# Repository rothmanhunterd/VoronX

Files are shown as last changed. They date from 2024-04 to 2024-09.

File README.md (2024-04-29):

# VoronX

VoronX is a large format 3D printer with a build volume of 800mm x 800mm by 800mm. This featues dual extruders which both run off 2.85mm filament. The 2.85mm filament enables larger nozzle sizes, for example the standard nozzle size for this printer is 2.4mm. This is a standard cartesian pritner with a flying gantry. The X and Y axis are driven independetly by two motors each. The Z axis is driven by 4 lead screws. This printer is configured with Klipper firmware and uses MainSail interface.

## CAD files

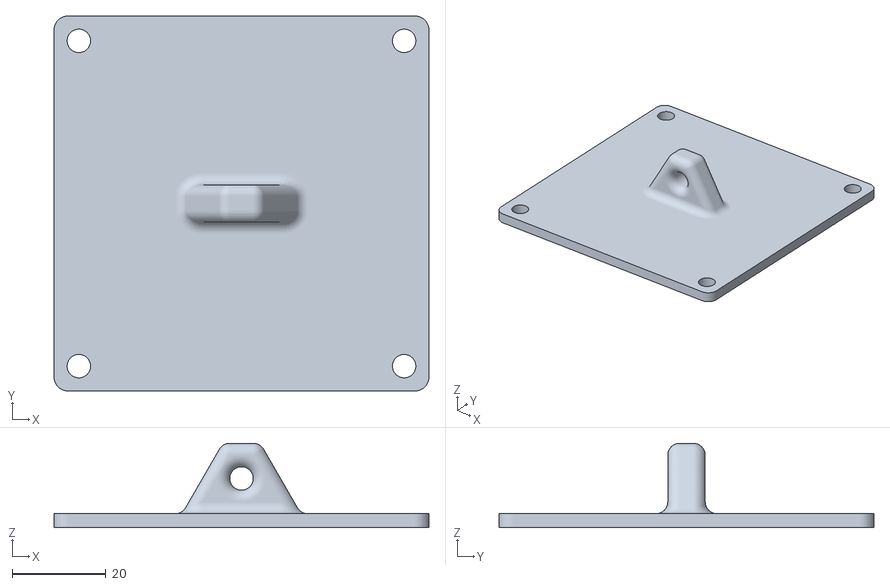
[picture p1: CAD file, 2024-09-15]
hardware/CAD_files/STLs/Counterweight/Weight_Top_Box.STL
80.0 x 80.0 x 18.0

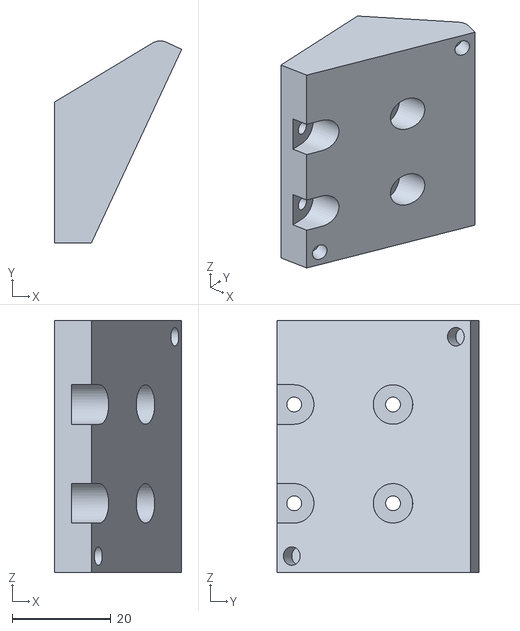
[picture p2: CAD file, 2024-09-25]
hardware/CAD_files/STLs/Part_Cooling_Fan/Part_Cooling_Mount_Left.STL
25.8 x 40.9 x 51.0

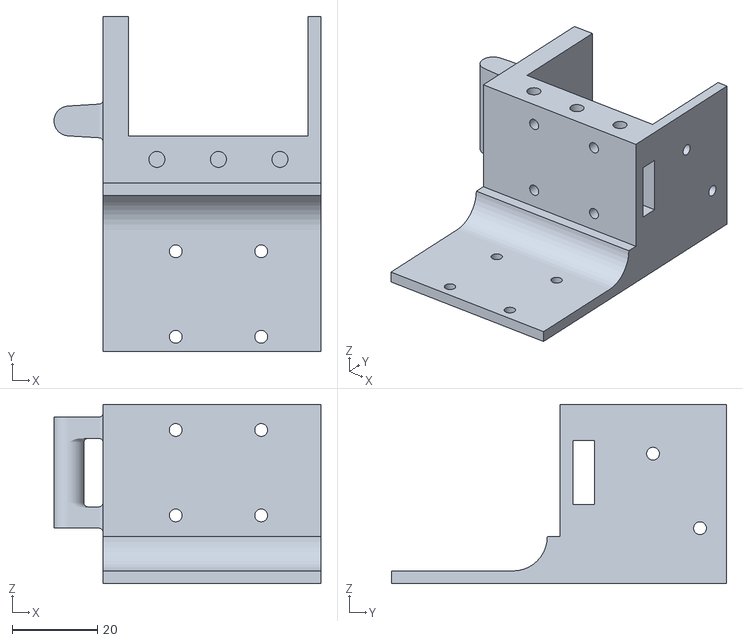
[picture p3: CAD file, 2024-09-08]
hardware/CAD_files/STLs/Print_Head_Mount_Right.STL
62.5 x 78.5 x 42.0

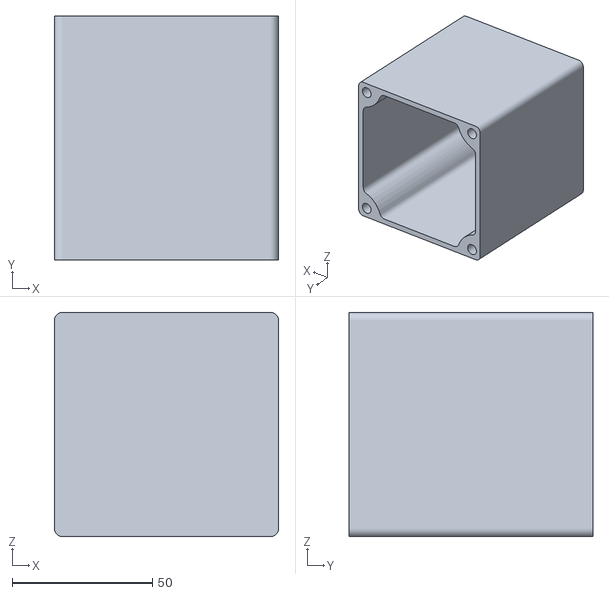
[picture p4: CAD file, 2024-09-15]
hardware/CAD_files/STLs/Counterweight/Weight_Bottom_Box.STL
80.0 x 87.0 x 80.0

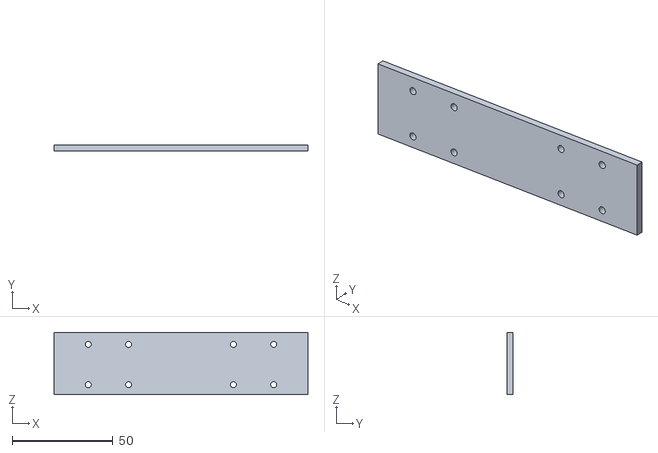
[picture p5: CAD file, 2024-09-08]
hardware/CAD_files/STLs/Connector_Plate.STL
126.0 x 3.00 x 31.0

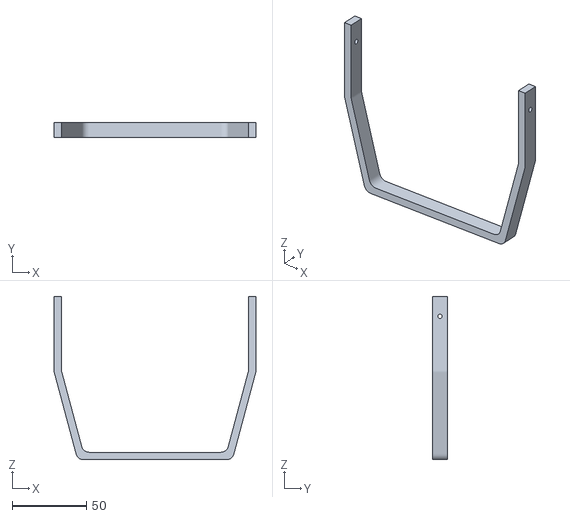
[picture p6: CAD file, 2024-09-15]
hardware/CAD_files/STLs/Counterweight/Tension_Bar.STL
136.0 x 10.0 x 110.0

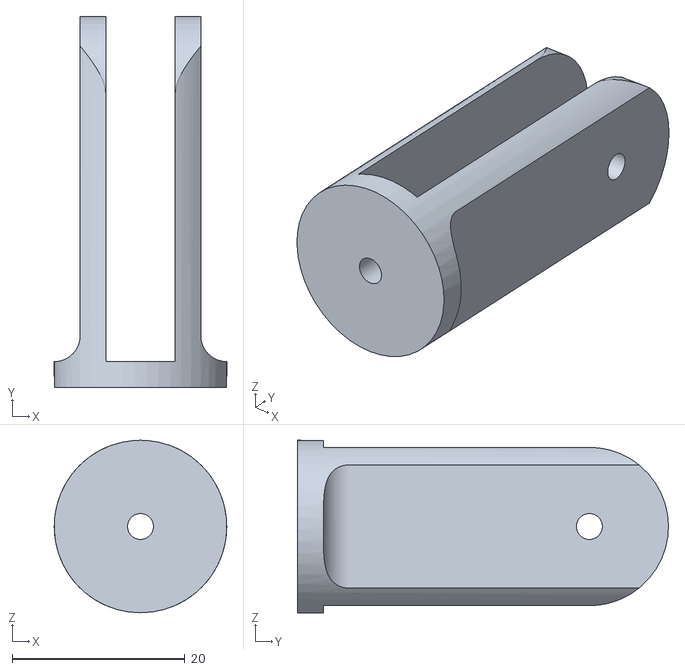
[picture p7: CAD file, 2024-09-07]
hardware/CAD_files/STLs/Cam_Frame_Mount.STL
20.0 x 43.0 x 20.0

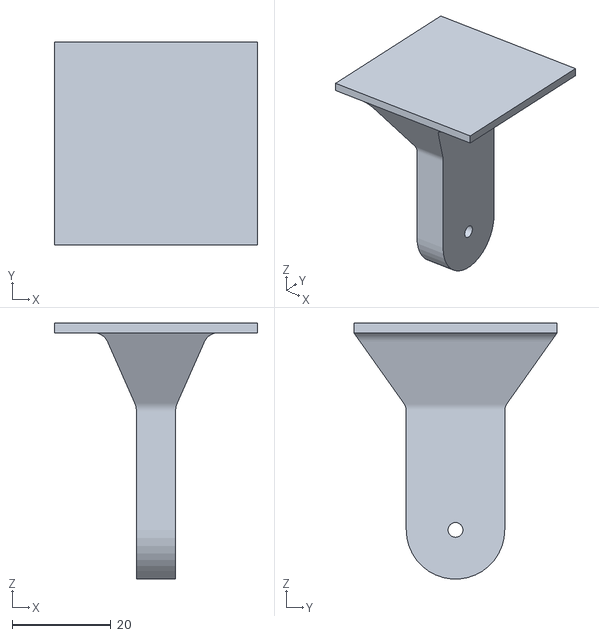
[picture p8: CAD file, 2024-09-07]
hardware/CAD_files/STLs/Cam_Cam_Mount.STL
41.3 x 41.3 x 52.0

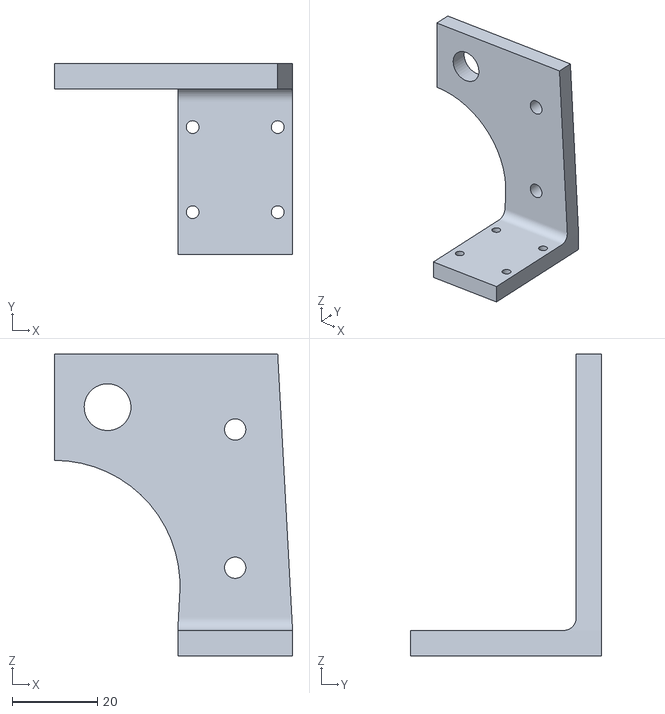
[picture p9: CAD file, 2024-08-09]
hardware/CAD_files/STLs/Gantry_Linear_Rail_Connector_Front_Left.STL
56.0 x 45.0 x 71.0

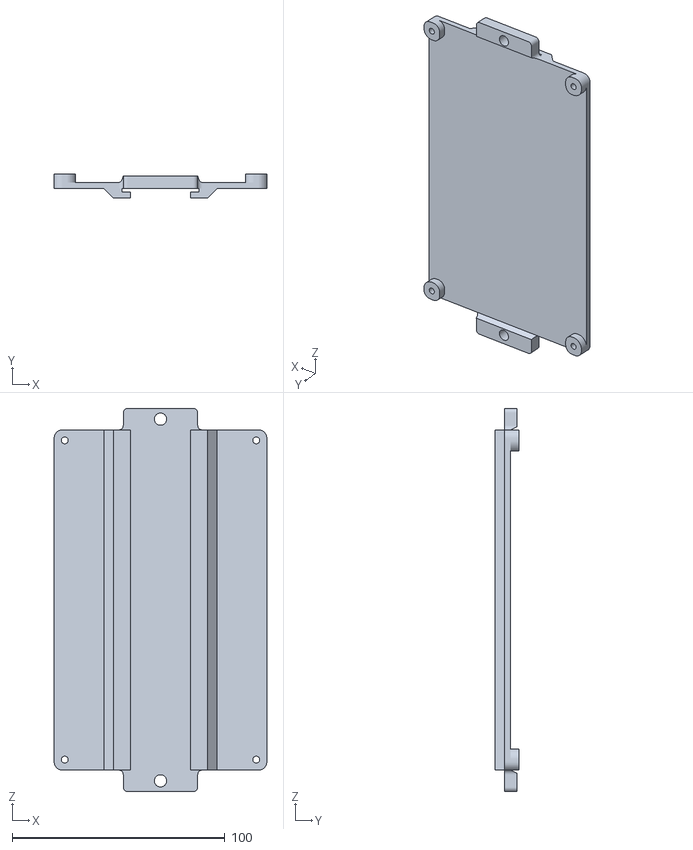
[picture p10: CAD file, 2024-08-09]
hardware/CAD_files/STLs/Octopus_Max_EZ_DIN_Mount.STL
100.0 x 11.5 x 180.0

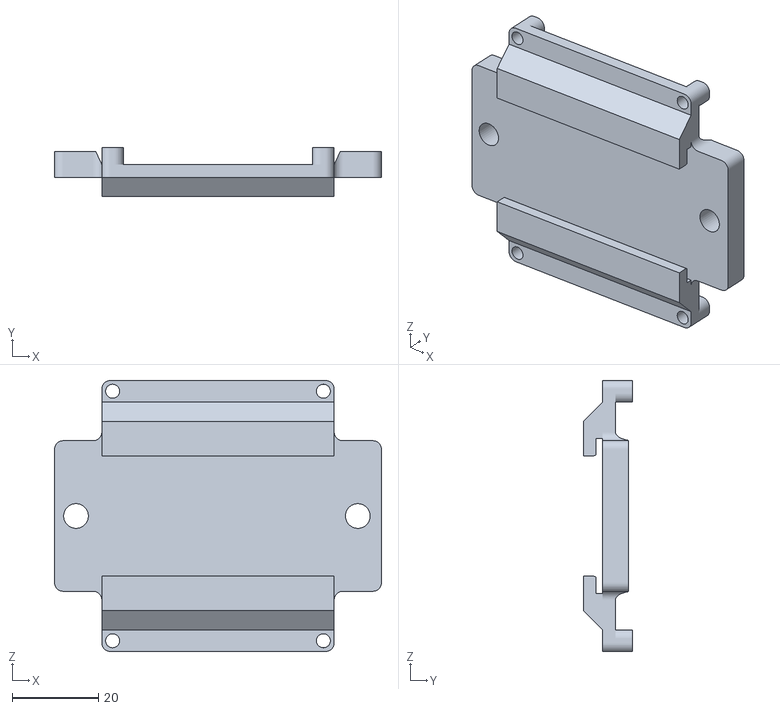
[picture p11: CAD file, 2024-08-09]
hardware/CAD_files/STLs/PI4B+CB1_DIN_Mount.STL
76.0 x 11.5 x 63.0

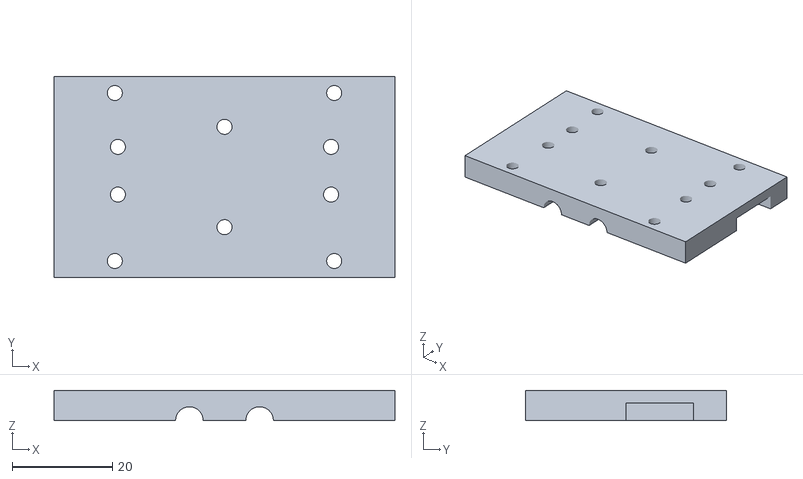
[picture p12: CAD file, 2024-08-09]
hardware/CAD_files/STLs/Filament_Sensor_Top.STL
68.0 x 40.0 x 6.00

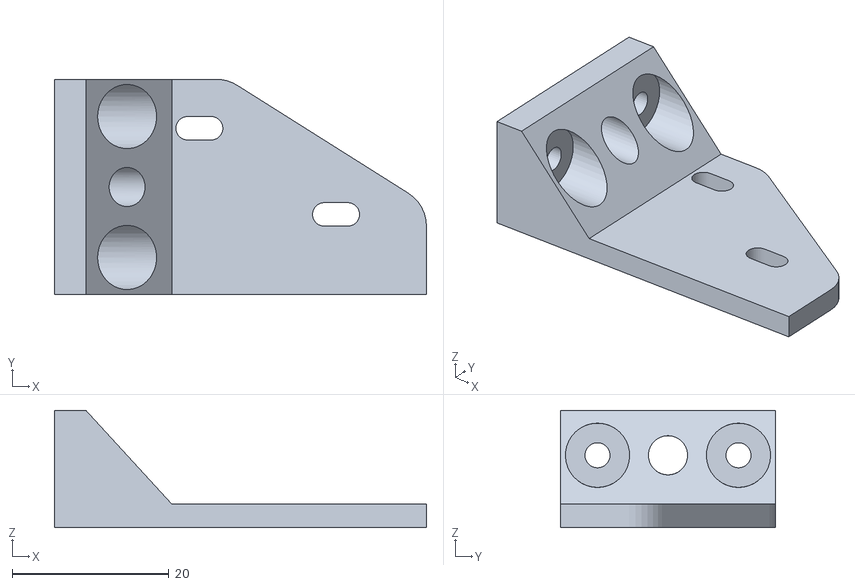
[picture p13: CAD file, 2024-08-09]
hardware/CAD_files/STLs/BLTouch_Mount.STL
47.5 x 27.5 x 15.0

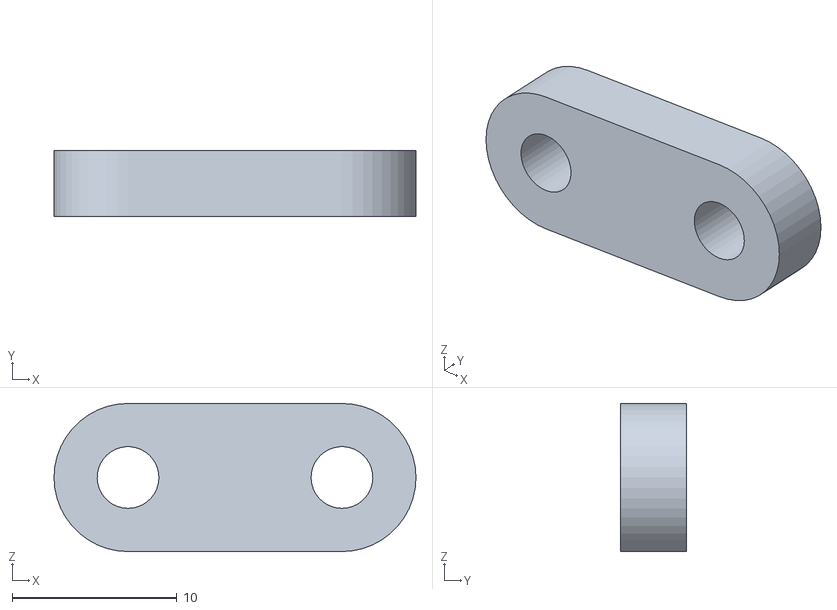
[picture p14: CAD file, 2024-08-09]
hardware/CAD_files/STLs/Belt_Clamp_Insert_Side.STL
22.0 x 4.00 x 9.00

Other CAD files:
hardware/CAD_files/STLs/Part_Cooling_Fan/Part_Cooling_Mount_Right.STL
hardware/CAD_files/STLs/Print_Head_Mount_Left.STL
hardware/CAD_files/STLs/Print_Head_Cable_Chain.STL
hardware/CAD_files/STLs/XY_Connector.STL
hardware/CAD_files/STLs/3mm_Bolt_Backplate.STL
hardware/CAD_files/STLs/5mm_Bolt_Backplate.STL
hardware/CAD_files/STLs/5mm_Extended_Bolt_Backplate.STL
hardware/CAD_files/STLs/6mm_Bolt_Backplate.STL
hardware/CAD_files/STLs/Bearing_Bracket.STL
hardware/CAD_files/STLs/Belt_Clamp_Bolt_Side.STL
hardware/CAD_files/STLs/Filament_Sensor_Bottom.STL
hardware/CAD_files/STLs/Foot_Pad.STL
hardware/CAD_files/STLs/Gantry_Linear_Rail_Connector_Back.STL
hardware/CAD_files/STLs/Gantry_Linear_Rail_Connector_Front_Right.STL
hardware/CAD_files/STLs/Limit_Switch_Mounts.STL
hardware/CAD_files/STLs/Power_Switch_Mount.STL
hardware/CAD_files/STLs/XY_Cable_Chain_Mount_Left.STL
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

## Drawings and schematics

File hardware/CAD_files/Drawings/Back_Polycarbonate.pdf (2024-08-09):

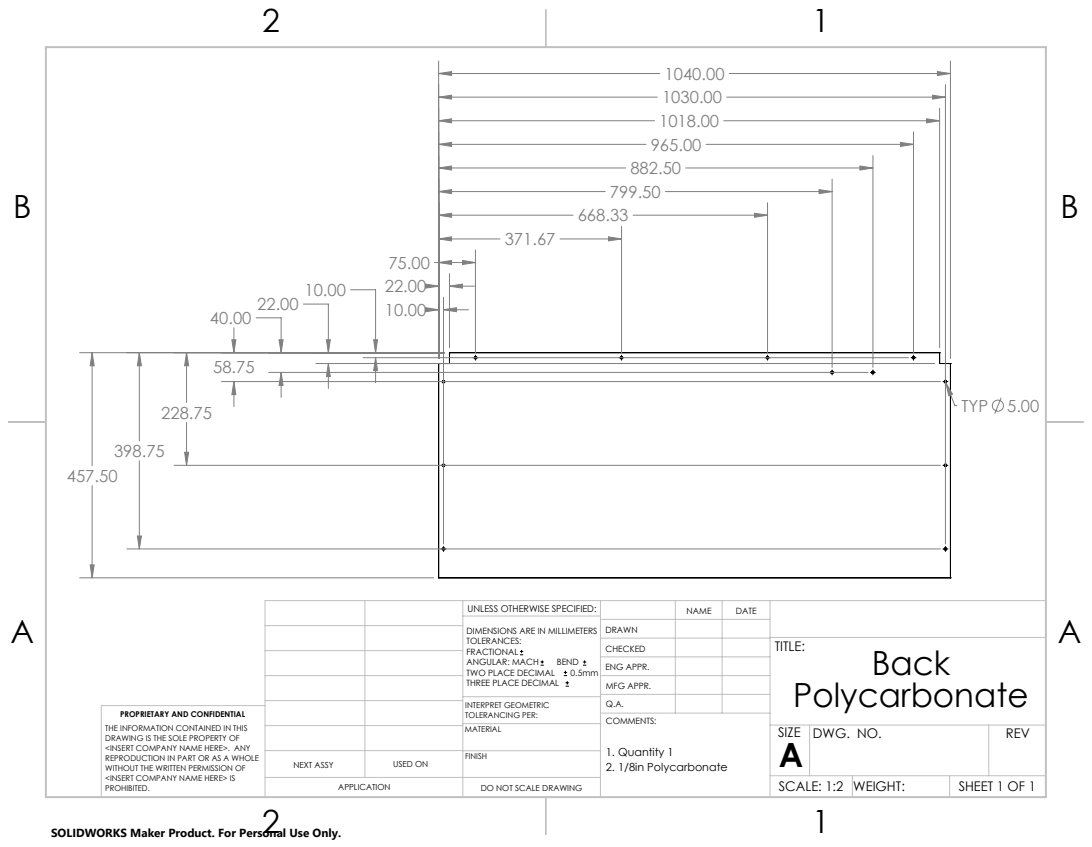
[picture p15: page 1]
TYP 5.00; 1. Quantity 1 2. 1/8in Polycarbonate

UNLESS OTHERWISE SPECIFIED: | | NAME | DATE
DIMENSIONS ARE IN MILLIMETERS TOLERANCES: FRACTIONAL ANGULAR: MACH BEND TWO PLACE DECIMAL 0.5mm THREE PLACE DECIMAL | DRAWN

CHECKED | | | TITLE: Back Polycarbonate

ENG APPR.
MFG APPR.

INTERPRET GEOMETRIC TOLERANCING PER: | Q.A.
MATERIAL | | SIZE A | DWG. NO. | REV

PROPRIETARY AND CONFIDENTIAL
THE INFORMATION CONTAINED IN THIS
DRAWING IS THE SOLE PROPERTY OF
<INSERT COMPANY NAME HERE>. ANY
REPRODUCTION IN PART OR AS A WHOLE
WITHOUT THE WRITTEN PERMISSION OF
<INSERT COMPANY NAME HERE> IS
PROHIBITED.

NEXT ASSY | USED ON | FINISH

APPLICATION | DO NOT SCALE DRAWING | | SCALE: 1:2 | WEIGHT: | SHEET 1 OF 1

SOLIDWORKS Maker Product. For Personal Use Only.

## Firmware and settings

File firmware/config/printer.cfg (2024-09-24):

# [include mainsail.cfg]
[include shell_command.cfg]
[include moonraker_obico_macros.cfg]
[include adxl.cfg]
[include macros.cfg]

[virtual_sdcard]
path: ~/printer_data/gcodes
on_error_gcode: CANCEL_PRINT

[mcu]
serial: /dev/serial/by-id/usb-Klipper_stm32h723xx_1C0006000F51313236343430-if00

[printer]
kinematics: cartesian
max_velocity: 50
max_accel: 375
max_z_velocity: 5
max_z_accel: 37.5
square_corner_velocity: 2

[board_pins]
aliases:
    # FPC header, Aliases EXP1 & EXP2 for mini12864
    EXP1_1=PG2, EXP1_2=PD15,
    EXP1_3=PD14, EXP1_4=PD13,
    EXP1_5=PD12, EXP1_6=PD11,
    EXP1_7=PD10, EXP1_8=PE15,
    EXP1_9=<GND>, EXP1_10=<5V>,

    # EXP2 header
    EXP2_1=PE13, EXP2_2=PE12,
    EXP2_3=PG5, EXP2_4=PE11,
    EXP2_5=PG4, EXP2_6=PE14,
    EXP2_7=PG3, EXP2_8=<RST>,
    EXP2_9=<GND>, EXP2_10=<NC>

# Motor-1, Left Motor
[stepper_x]
step_pin: PC13
dir_pin: PC14
enable_pin: !PE6
microsteps: 16
rotation_distance: 79.168
endstop_pin: PF0
position_endstop: -72
position_min: -72
position_max: 540
homing_speed: 20

# Motor-2, Right Motor
[stepper_x1]
step_pin: PE4
dir_pin: PE5
enable_pin: !PE3
microsteps: 16
rotation_distance: 79.168

# Motor-3, Left Motor
[stepper_y]
step_pin: PE1
dir_pin: PE0
enable_pin: !PE2
microsteps: 16
rotation_distance: 79.168
endstop_pin: PF2
position_endstop: 660
position_max: 660
homing_speed: 20

# Motor-4, Right Motor
[stepper_y1]
step_pin: PB8
dir_pin: !PB9
enable_pin: !PB7
microsteps: 16
rotation_distance: 79.168

# Motor-5, Left Motor
[extruder]
step_pin: PB5
dir_pin: PB4
enable_pin: !PB6
microsteps: 16
rotation_distance: 14.712
nozzle_diameter: 2.400
filament_diameter: 2.850
pressure_advance: 0.0
pressure_advance_smooth_time: 0.040
heater_pin: PF6 # HE0
sensor_pin:  PB0 # T0
sensor_type: ATC Semitec 104GT-2
#control: pid
#pid_Kp: 22.2
#pid_Ki: 1.08
#pid_Kd: 114
min_extrude_temp: 190
min_temp: 0
max_temp: 300

# Motor-6, Right Motor
[extruder1]
step_pin: PG15
dir_pin: PB3
enable_pin: !PD5
microsteps: 16
rotation_distance: 14.712
nozzle_diameter: 2.400
filament_diameter: 2.850
pressure_advance: 0.0
pressure_advance_smooth_time: 0.040
heater_pin: PA0 # HE1
sensor_pin: PC5 # T1
sensor_type: ATC Semitec 104GT-2
#control: pid
#pid_Kp: 22.2
#pid_Ki: 1.08
#pid_Kd: 114
min_extrude_temp: 190
min_temp: 0
max_temp: 300

# Gcode Needs Tuned
[filament_switch_sensor T0_filament]
switch_pin: PF1
runout_gcode:
    G91
    G1 Z5
    M84

# Gcode Needs Tuned
[filament_switch_sensor T1_filament]
switch_pin: PC15
runout_gcode:
    G91
    G1 Z5
    M84

# Motor-7, Front Left
[stepper_z]
step_pin: PD3
dir_pin: PD2
enable_pin: !PD4
microsteps: 16
rotation_distance: 16
endstop_pin: probe:z_virtual_endstop
position_max: 675
homing_speed: 5

# Motor-8, Back Left
[stepper_z1]
step_pin: PA10
dir_pin: PA9
enable_pin: !PA15
microsteps: 16
rotation_distance: 16

# Motor-9, Back Right
[stepper_z2]
step_pin: PA8
dir_pin: PC7
enable_pin: !PC9
microsteps: 16
rotation_distance: 16

# Motor-10, Front Right
[stepper_z3]
step_pin: PG6
dir_pin: PC6
enable_pin: !PC8
microsteps: 16
rotation_distance: 16

[heater_bed]
heater_pin: PF5
sensor_pin: PB1 # TB
sensor_type: NTC 100K MGB18-104F39050L32
control: watermark
min_temp: 0
max_temp: 100

[verify_heater heater_bed]
max_error: 840
check_gain_time: 420

[safe_z_home]
home_xy_position: 234, 330
z_hop: 5
z_hop_speed: 5
speed: 20

[quad_gantry_level]
gantry_corners:
    -201.51, -92.75
    741.49, 850.25
points:
    10, 10
    10, 650
    530, 650
    530, 10
speed: 20
horizontal_move_z: 10
retries: 3
retry_tolerance: 0.05

[bed_mesh]
mesh_min: 10, 10
mesh_max: 530, 650
speed: 20
probe_count: 10, 10
algorithm: bicubic
adaptive_margin: 5
horizontal_move_z: 10

[bltouch]
sensor_pin: ^PB15
control_pin: PB14
x_offset: 33.25
y_offset: -6
z_offset: 1.55

[heater_fan hot_fan]
pin: PA6
heater: extruder
heater_temp: 50.0

[heater_fan hot_fan1]
pin: PA4
heater: extruder1
heater_temp: 50.0

[multi_pin part_cooling_pins]
pins: PA5, PA3

[fan]
pin: multi_pin:part_cooling_pins

[input_shaper]
#shaper_type_x: mzv
#shaper_type_y: mzv
#shaper_freq_x: 0
#shaper_freq_y: 0

[display_status]

[pause_resume]
recover_velocity: 20

[idle_timeout]
timeout: 7200

[force_move]
enable_force_move: True

[exclude_object]

[skew_correction]

#*# <---------------------- SAVE_CONFIG ---------------------->
#*# DO NOT EDIT THIS BLOCK OR BELOW. The contents are auto-generated.
#*#
#*# [extruder]
#*# control = pid
#*# pid_kp = 23.729
#*# pid_ki = 1.478
#*# pid_kd = 95.212
#*#
#*# [extruder1]
#*# control = pid
#*# pid_kp = 23.002
#*# pid_ki = 1.289
#*# pid_kd = 102.647
#*#
#*# [input_shaper]
#*# shaper_type_x = zv
#*# shaper_freq_x = 21.0
#*# shaper_type_y = mzv
#*# shaper_freq_y = 23.0
#*#
#*# [bed_mesh default]
#*# version = 1
#*# points =
#*# 	0.530000, 0.460000, 0.430000, 0.475000, 0.490000, 0.470000, 0.465000, 0.495000, 0.560000, 0.645000
#*# 	0.650000, 0.565000, 0.540000, 0.545000, 0.550000, 0.540000, 0.545000, 0.580000, 0.625000, 0.670000
#*# 	0.490000, 0.370000, 0.270000, 0.230000, 0.200000, 0.215000, 0.240000, 0.280000, 0.340000, 0.385000
#*# 	0.505000, 0.390000, 0.310000, 0.285000, 0.275000, 0.270000, 0.285000, 0.340000, 0.390000, 0.400000
#*# 	0.510000, 0.330000, 0.190000, 0.125000, 0.065000, 0.055000, 0.100000, 0.155000, 0.205000, 0.230000
#*# 	0.495000, 0.320000, 0.200000, 0.160000, 0.125000, 0.120000, 0.160000, 0.215000, 0.270000, 0.260000
#*# 	0.490000, 0.295000, 0.155000, 0.040000, -0.020000, -0.035000, 0.015000, 0.100000, 0.175000, 0.220000
#*# 	0.510000, 0.315000, 0.170000, 0.100000, 0.070000, 0.075000, 0.130000, 0.215000, 0.295000, 0.325000
#*# 	0.635000, 0.420000, 0.250000, 0.145000, 0.060000, 0.050000, 0.120000, 0.230000, 0.355000, 0.450000
#*# 	0.980000, 0.585000, 0.350000, 0.215000, 0.165000, 0.195000, 0.280000, 0.400000, 0.525000, 0.615000
#*# x_count = 10
#*# y_count = 10
#*# mesh_x_pps = 2
#*# mesh_y_pps = 2
#*# algo = bicubic
#*# tension = 0.2
#*# min_x = 10.0
#*# max_x = 529.9300000000001
#*# min_y = 10.0
#*# max_y = 649.99

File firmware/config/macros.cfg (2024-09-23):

[gcode_macro START_PRINT]
gcode:
    {% set BED_TEMP = params.BED_TEMP|default(0)|float %}
    {% set EXTRUDER_TEMP = params.EXTRUDER_TEMP|default(190)|float %}

    G92 E0
    G28

    G91
    G1 Z5 F300

    G90
    G1 X10 Y650 F1500

    M190 S{BED_TEMP}

    QUAD_GANTRY_LEVEL
    BED_MESH_CALIBRATE ADAPTIVE=1

    G1 X10 Y650

    M109 S{EXTRUDER_TEMP}

[gcode_macro END_PRINT]
gcode:
    TURN_OFF_HEATERS
    M106 S0 

    G91
    G1 Z5 F300

    G90
    G1 X10 Y650 F1500

[gcode_macro PAUSE]
rename_existing: BASE_PAUSE
gcode:
    BASE_PAUSE

[gcode_macro RESUME]
rename_existing: BASE_RESUME
gcode:
    BASE_RESUME VELOCIY=20

[gcode_macro CLEAR_PAUSE]
rename_existing: BASE_CLEAR_PAUSE
gcode:
    BASE_CLEAR_PAUSE

[gcode_macro CANCEL_PRINT]
rename_existing: BASE_CANCEL_PRINT
gcode:
    BASE_CANCEL_PRINT

    END_PRINT

[gcode_macro T0]
gcode:
    SET_GCODE_OFFSET X=0 Y=0 Z=0
    ACTIVATE_EXTRUDER EXTRUDER=extruder

[gcode_macro T1]
gcode:
    SET_GCODE_OFFSET X=-72 Y=0 Z=0
    ACTIVATE_EXTRUDER EXTRUDER=extruder1

[gcode_macro T0_SLICER_START]
gcode:
    T0

[gcode_macro T0_SLICER_END]
gcode:

[gcode_macro T1_SLICER_START]
gcode:
    T1

[gcode_macro T1_SLICER_END]
gcode:

[gcode_macro PRESENT_PRINTHEAD]
gcode:
    T0
    G90
    G1 X234 Y0 Z200
    M84

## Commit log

2024-04-29 Upload Initial Klipper Config File
    [VoronX-Klipper-Config.cfg]
2024-04-29 Update Name, Remove Comments
    [VoronX-Klipper-Config.cfg]
2024-04-29 Remove Config
    [VoronX-Klipper-Config.cfg]
2024-04-29 Upload Initial Config
    [voronx-klipper-config.cfg]
2024-04-30 Add Specifics to Exitsing Attributes
    [voronx-klipper-config.cfg]
2024-04-30 Set Bed Temp Probe Type
    [voronx-klipper-config.cfg]
2024-05-01 Change Names for Readability
    [voronx-klipper-config.cfg]
2024-05-01 Organize and Remove Config Sections
    [voronx-klipper-config.cfg]
2024-05-01 Rename Filament Sensors
    [voronx-klipper-config.cfg]
2024-05-01 Add Retraction Message Capability
    [voronx-klipper-config.cfg]
2024-05-08 Upload Resonance Tester Config
    [voronx-klipper-config.cfg]
2024-06-10 Include Axes Map for ADXL345
    [voronx-klipper-config.cfg]
2024-06-12 Label Stepper Locations
    [voronx-klipper-config.cfg]
2024-06-13 Add Gcode Macros for Changing Current Extruder
    [voronx-klipper-config.cfg]
2024-06-13 Update Access Extruder Macro
    [voronx-klipper-config.cfg]
2024-06-13 Rename access_print_head Macro
    [voronx-klipper-config.cfg]
2024-06-13 Update Macro Formatting
    [voronx-klipper-config.cfg]
2024-06-13 Set Extruder Offset
    [voronx-klipper-config.cfg]
2024-06-14 Set Homing Speeds, Endstop Positions
    [voronx-klipper-config.cfg]
2024-06-14 Add Exclude Object
    [voronx-klipper-config.cfg]
2024-06-17 Add Start, Stop Gcode Headers
    [voronx-klipper-config.cfg]
2024-06-17 Add Fan Configs
    [voronx-klipper-config.cfg]
2024-07-02 Add Virtual SDCard
    [voronx-klipper-config.cfg]
2024-07-10 Change Macro Name
    [voronx-klipper-config.cfg]
2024-07-10 Update Names
    [voronx-config.cfg]
2024-07-15 Add Status Comments
    [voronx-config.cfg]
2024-07-15 Comment Out Additional Features
    [voronx-config.cfg]
2024-08-08 Setup Fans
    [voronx-config.cfg]
2024-08-08 Fix Names
    [voronx-config.cfg]
2024-08-08 Set Nominal Rotation Distances
    [voronx-config.cfg]
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2024-08-09 Remove Unnecessary Retraction Object
    [voronx-config.cfg]
2024-08-09 Reformat Comments
    [voronx-config.cfg]
2024-08-09 Reformat More Comments
    [voronx-config.cfg]
2024-08-09 Upload Full Cad, Drawings, and STLs
    [3mm_Bolt_Backplate.STL, 5mm_Bolt_Backplate.STL, 5mm_Extended_Bolt_Backplate.STL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]
2024-08-12 Update Endstop Pins
    [voronx-config.cfg]
2024-08-12 Setup test_bltouch Macro
    [voronx-config.cfg]
2024-08-12 Update Printer Name
    [vulcan750-config.cfg]
2024-08-13 Remove Unnecessary Double Definitions
    [vulcan750-config.cfg]
2024-08-14 Remove Unnecessary Quad Level Parameters
    [vulcan750-config.cfg]
2024-08-14 Remove LEDs
    [vulcan750-config.cfg]
2024-08-19 Add Bed Mesh Object
    [vulcan750-config.cfg]
2024-08-19 Set z-hop
    [vulcan750-config.cfg]
2024-08-19 Update to Printer Moving
    [vulcan750-config.cfg]
2024-08-19 Update with mainsail.cfg
    [vulcan750-config.cfg]
2024-08-20 Update Rotation Distance, Max Travels
    [vulcan750-config.cfg]
2024-08-20 Update quad_gantry_level and bed_mesh
    [vulcan750-config.cfg]
2024-08-20 Remove Unnecessary Comments
    [vulcan750-config.cfg]
2024-08-21 Remove Comments
    [vulcan750-config.cfg]
2024-08-21 Set bltouch Offsets
    [vulcan750-config.cfg]
2024-08-23 Update Quad Gantry Level, Bed Mesh
    [vulcan750-config.cfg]
2024-08-24 Update BLTouch Offset
    [vulcan750-config.cfg]
2024-09-05 Update From Git Backup
    [vulcan750-config.cfg]
2024-09-05 Update with Heater, Macro Tests
    [vulcan750-config.cfg]
2024-09-06 Input Shaper Functional
    [vulcan750-config.cfg]
2024-09-06 Include Config File
    [adxl.cfg, moonraker-obico-update.cfg, moonraker-obico.cfg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]
2024-09-06 Add Camera Mount STLs
    [Cam_Cam_Mount.STL, Cam_Frame_Mount.STL]
2024-09-07 Update Camera Mounts
    [Cam_Cam_Mount.STL, Cam_Frame_Mount.STL]
2024-09-08 Update Printhead Mounts
    [Connector_Plate.STL, Print_Head_Mount_Left.STL, Print_Head_Mount_Right.STL]
2024-09-09 Update Due to mainsail.cfg Changes
    [printer.cfg]
2024-09-09 Put Macros into Separate File
    [macros.cfg, printer.cfg]
2024-09-09 Config Part Cooling Fans
    [printer.cfg]
2024-09-09 Enable exclude_object, skew_correction
    [printer.cfg]
2024-09-09 Fix Pin Number for Part Cooling Fan
    [printer.cfg]
2024-09-09 Include macros.cfg
    [printer.cfg]
2024-09-10 Fix Multi Pin Usage
    [printer.cfg]
2024-09-10 Initial Test Macros for Print Functions
    [macros.cfg]
2024-09-10 Cooldown Extruders on Pause
    [macros.cfg]
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2024-09-10 Revert to Functioning Lack of Macros
    [macros.cfg, printer.cfg]
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2024-09-16 Add Toolhead Macros for Slicer
    [macros.cfg]
2024-09-16 Set Macro Naming Convention
    [macros.cfg]
2024-09-16 Basic Config for Toolhead Macros
    [macros.cfg]
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2024-09-16 Add QGL and Bed Mesh
    [macros.cfg]
2024-09-16 Set Initial Z Height
    [macros.cfg]
2024-09-16 Revert Previous Commit
    [macros.cfg]
2024-09-17 Start, End, Cancel Functional
    [macros.cfg, printer.cfg]
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2024-09-23 Set Stow Point and Extruder Rotation Distance
    [macros.cfg, printer.cfg]
2024-09-23 Set Bed and Home Parameters
    [printer.cfg]
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2024-09-24 Reset Values
    [printer.cfg]
2024-09-24 Set Square Corner Velocity
    [printer.cfg]
2024-09-25 Part Cooling Fan Mount
    [Part_Cooling_Mount_Left.STL, Part_Cooling_Mount_Right.STL]
